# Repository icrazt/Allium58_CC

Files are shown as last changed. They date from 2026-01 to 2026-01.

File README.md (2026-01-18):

# personal keyboard build

原始项目: https://github.com/beekeeb/Allium58

ZMK配置: https://github.com/icrazt/zmk-config

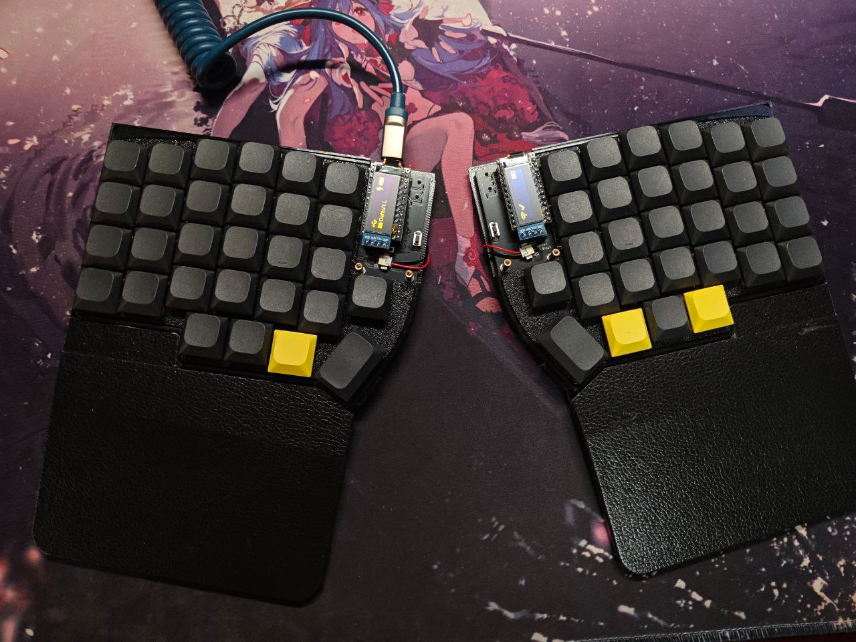
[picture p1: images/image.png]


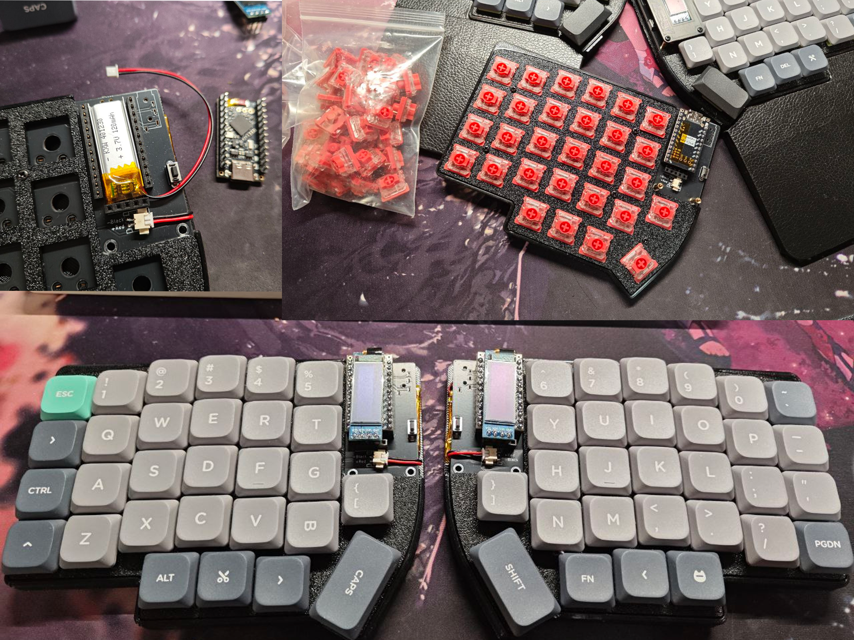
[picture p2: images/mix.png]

---

# Allium58 无线键盘物料清单 (Bill of Materials) 

以下清单基于我构建 Allium58 (Lily58 衍生版) 时的实际采购记录整理，价格仅供参考（基于淘宝/闲鱼历史订单）。

### 1. 核心电子元件 (Core Electronics)

| 项目 (Item) | 规格/型号 (Specs) | 购买数量 | 参考价格 (CNY) | 备注 (Notes) |
| --- | --- | --- | --- | --- |
| **主控板** | Promicro NRF52840 开发板 | 2 个 | ¥23.78 (¥11.89/个) | 替代 Nice!Nano，用于无线蓝牙连接 |
| **热插拔轴座** | 佳达隆 (Gateron) 矮轴热插拔轴座 | 70 颗 | ¥27.16 | 专用于矮轴 (Low Profile)，Allium58通常需要58个 |
| **二极管** | 1N4148W (T4) | 100 个 | ¥4.00 | 封装：SOD-123，贴片二极管 |
| **复位开关** | `3*6*5mm` 直插2脚轻触开关 | 20 个 | ¥2.16 | Reset 按钮，用于进入刷机模式 |

### 2. 无线与电源 (Wireless & Power)

| 项目 (Item) | 规格/型号 (Specs) | 购买数量 | 参考价格 (CNY) | 备注 (Notes) |
| --- | --- | --- | --- | --- |
| **锂电池** | 401230 聚合物锂电池 | 2 个 | ¥10.1 (¥5.05/个) | 3.7V 120mAh，尺寸适合放入主控下方 |
| **电源开关** | MSK-12C01-07 拨动开关 | 10 个 | ¥1.96 | 7脚贴片，用于切断电池供电 |

### 3. 显示与排针 (Display & Headers)

| 项目 (Item) | 规格/型号 (Specs) | 购买数量 | 参考价格 (CNY) | 备注 (Notes) |
| --- | --- | --- | --- | --- |
| **OLED 屏幕** | 0.91寸 OLED 液晶屏 | 2 个 | ¥10 (¥5/个)  | I2C接口，SSD1306驱动 (128x32分辨率) |
| **排母 (主控座)** | 2.54mm 单排母 12Pin H3.5 | 10 条 | ¥0.70 | 用于主控热插拔，建议使用低高度(H3.5)排母以降低厚度 |
| **排针** | 2.54mm 单排针 12Pin L7.5 | 10 条 | ¥0.14 | 焊在主控板上,L7.5搭配H3.5排母使用 |
| **排母 (显示屏)** | 2.54mm 单排母 5Pin | 10 条 | ¥0.70 | 标准排母即可 |

### 4. 外观与组装配件 (Mechanical & Hardware)

| 项目 (Item) | 规格/型号 (Specs) | 购买数量 | 参考价格 (CNY) | 备注 (Notes) |
| --- | --- | --- | --- | --- |
| **矮轴** | 佳达隆矮轴 越橘/芦荟 | 60 | ¥110 | 闲鱼购买，实际使用58颗，按个人手感喜好选择轴体 |
| **键帽** | DNDKB 矮轴超薄 JWA 高度 | 135 键 | ¥41.41 | 无刻/黑灰色，适配矮轴，按实际需要数量购买即可 |
| **螺丝** | M2*4 沉头螺丝 (黑色) | 1000 个 | ¥7.52 | 实际用量很少，买多是为了备用 |
| **铜柱** | M2*5 双通六角铜柱 | 50 个 | ¥1.07 | 用于固定PCB与底板/顶板 |
| **绝缘胶带** | 金手指高温胶带 (Kapton Tape) | 1 卷 | ¥0.10 | 5mm宽，用于显示器-主控绝缘 |

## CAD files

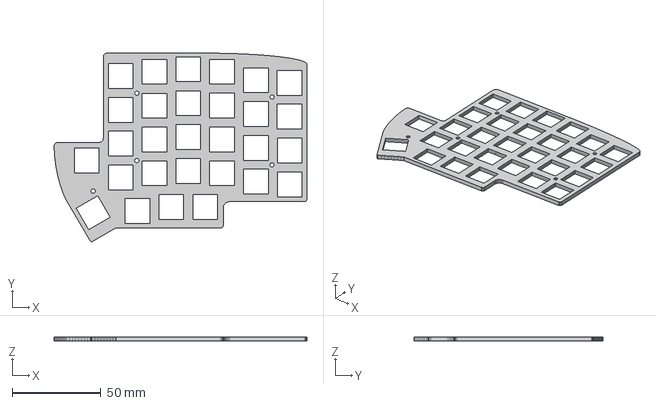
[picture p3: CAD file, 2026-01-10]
print/low-profile-case-for-allium58-glp-with-lily58-pro-layout-model_files/allium58-top-switch-plate.step
142.5 x 106.3 x 2.50 mm

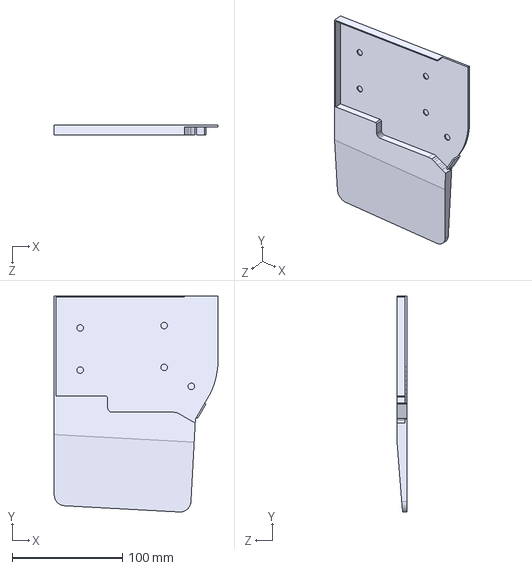
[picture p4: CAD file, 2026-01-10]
print/键盘手托L.STEP
148.4 x 196.0 x 9.00 mm

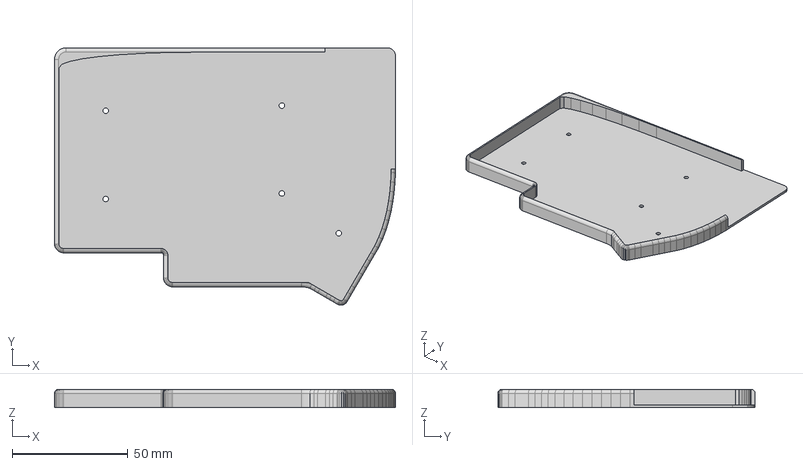
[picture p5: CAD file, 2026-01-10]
solidworks/allium58-bottom-case.step
147.5 x 111.3 x 8.00 mm

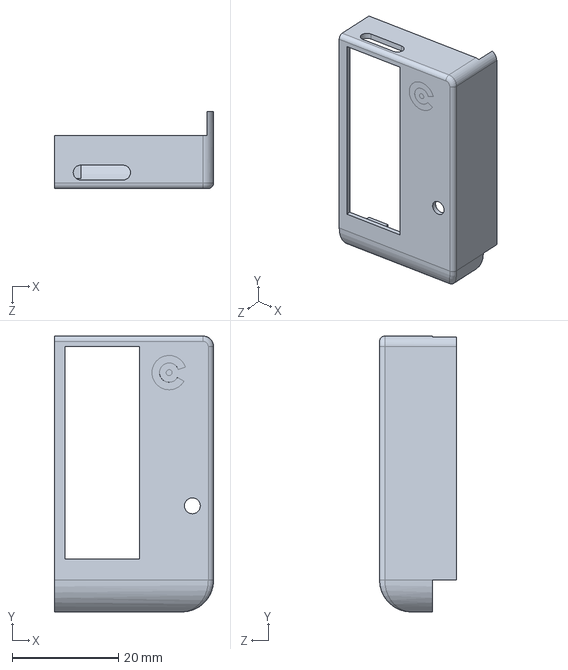
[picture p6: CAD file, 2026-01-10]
solidworks/屏幕保护壳.SLDPRT
30.0 x 52.0 x 14.5 mm

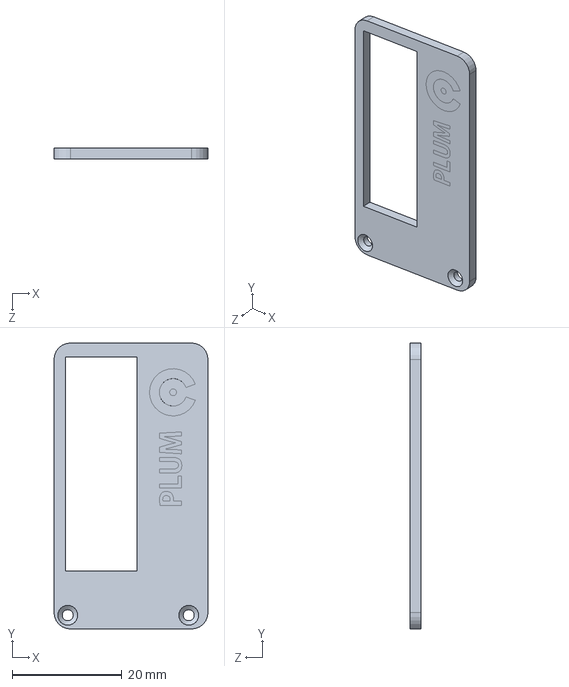
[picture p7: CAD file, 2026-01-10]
solidworks/屏幕边框.SLDPRT
28.0 x 52.0 x 2.00 mm

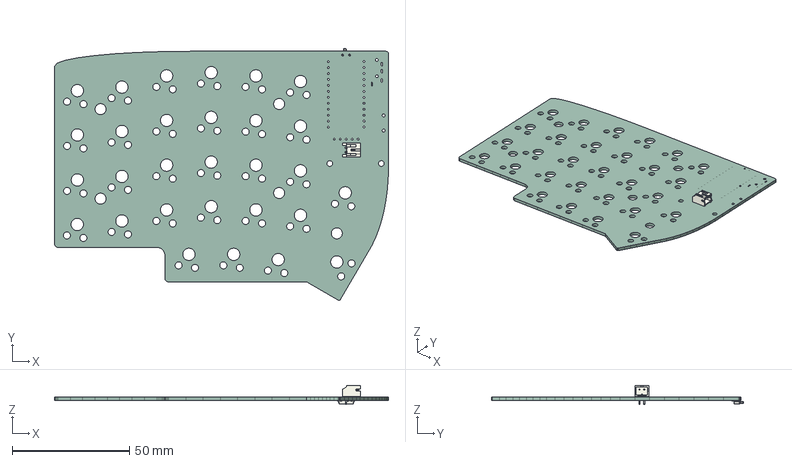
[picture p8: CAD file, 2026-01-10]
solidworks/allium58.step
142.5 x 107.5 x 8.25 mm
JST_PH_S2B-PH-K_1x02_P2.00mm_Horizontal
SW_SPDT_PCM12
allium58_PCB

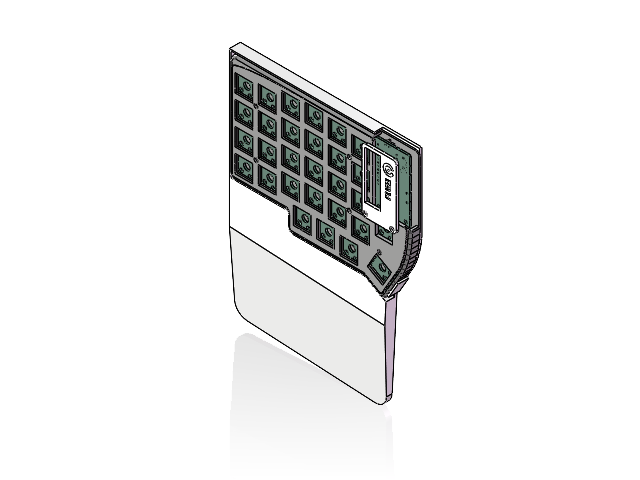
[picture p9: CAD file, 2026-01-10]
solidworks/键盘手托.SLDASM
allium58-bottom-case.step
键盘手托L
JST_PH_S2B-PH-K_1x02_P2.00mm_Horizontal.step
SW_SPDT_PCM12.step
allium58_PCB.step
allium58-top-switch-plate
屏幕边框

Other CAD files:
print/low-profile-case-for-allium58-glp-with-lily58-pro-layout-model_files/allium58-bottom-case.3mf
print/low-profile-case-for-allium58-glp-with-lily58-pro-layout-model_files/allium58-bottom-case.stl
print/low-profile-case-for-allium58-glp-with-lily58-pro-layout-model_files/allium58-top-switch-plate.3mf
print/low-profile-case-for-allium58-glp-with-lily58-pro-layout-model_files/allium58-top-switch-plate.stl
print/键盘手托.3mf
solidworks/allium58-top-switch-plate.SLDPRT
solidworks/键盘手托L.SLDPRT

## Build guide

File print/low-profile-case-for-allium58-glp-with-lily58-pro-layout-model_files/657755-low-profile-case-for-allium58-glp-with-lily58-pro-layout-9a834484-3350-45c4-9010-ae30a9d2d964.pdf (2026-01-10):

## Low Profile Case for Allium58 GLP

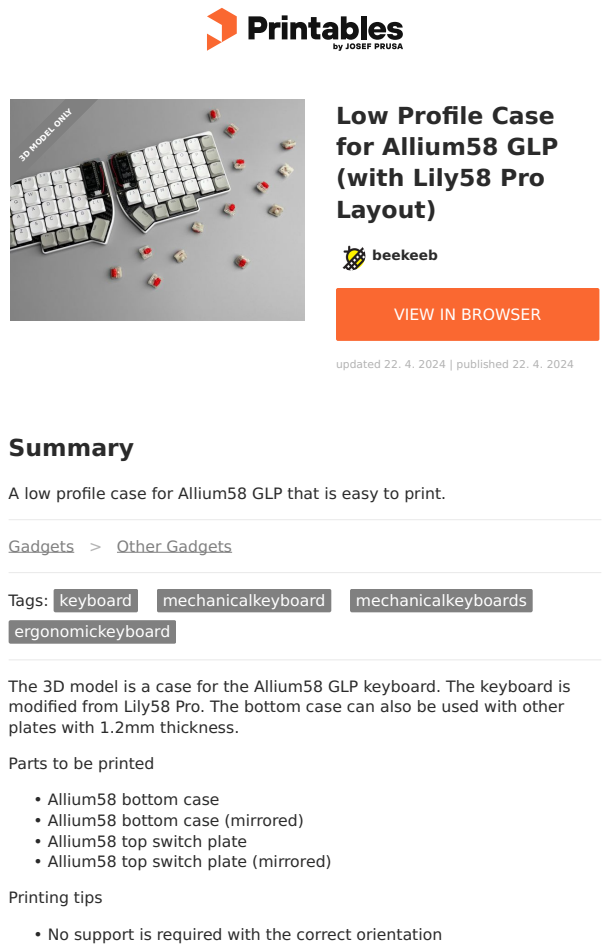
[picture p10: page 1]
Summary; Tags:; keyboard; mechanicalkeyboard; mechanicalkeyboards; ergonomickeyboard; Printing tips; beekeeb; (with Lily58 Pro Layout); updated 22. 4. 2024 | published 22. 4. 2024; 3D MODEL ONLY

VIEW IN BROWSER (https://printables.com/model/657755-low-profile-case-for-allium58-glp-with-lily58-pro)

A low profile case for Allium58 GLP that is easy to print.

Gadgets (https://printables.com/model?categoryId=21) > Other Gadgets (https://printables.com/model?categoryId=43)

The 3D model is a case for the Allium58 GLP keyboard. The keyboard is
modified from Lily58 Pro. The bottom case can also be used with other
plates with 1.2mm thickness.

Parts to be printed

Allium58 bottom case
Allium58 bottom case (mirrored)
Allium58 top switch plate
Allium58 top switch plate (mirrored)

No support is required with the correct orientation

## Model files

Parts required

20x GB823 screws M2*4mm
10x M2*5mm brass spacers
some rubber feet

Assembly tips

The brass inserts are placed between the top switch plate, and the bottom case.
On the top plate, there are cutouts for the brass inserts.

The PCB source file can be found at https://github.com/beekeeb/Allium58

This model is licensed under a Creative Commons (4.0 International License) Attribution. Please remember to attribute.

## License

This work is licensed under a
Creative Commons (4.0 International License)

Attribution (http://creativecommons.org/licenses/by/4.0/)

•
•
•

•

•

allium58-bottom-case.step

allium58-top-switch-plate.step

allium58-top-switch-plate.stl

allium58-bottom-case.stl

✖ | Sharing without ATTRIBUTION
✔ | Remix Culture allowed
✔ | Commercial Use
✔ | Free Cultural Works
✔ | Meets Open Definition

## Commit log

2026-01-10 init repo.
    [allium58-bottom-case.3mf, allium58-bottom-case.step, allium58-bottom-case.stl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]
2026-01-18 Add bom.
2026-01-18 update bom
2026-01-18 Update BOM to correct lithium battery pricing
2026-01-18 Update OLED screen price in BOM to reflect accurate cost
2026-01-18 Fix typo in reset switch description in README.md
